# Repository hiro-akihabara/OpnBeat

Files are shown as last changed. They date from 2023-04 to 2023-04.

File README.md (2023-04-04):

# About the Project
OpnBeat is Arduino based open source Lo-fi sampler project.<br>
It's designed to be low cost, easy to understand, to use and to make.

<br>
3D rendered image by Blender

<br>
PCB

<a href="http://www.youtube.com/watch?feature=player_embedded&v=SjGH37jxioc
" target="_blank">IMAGE ALT TEXT HERE</a><br>
Demo video

# Why this project is beneficial

# Project Status
I have just developed its prototype (Ver.3), POC (Proof of concept), MVP (Minimum Viable Product) whatever it's called including hardware. But I need supports especially about improving its farmware because I'm mainly an electric engineer and not so good at programming.

# Links
* project on Hackaday.io<br>
[OpnBeat / DIY Lo-fi Sampler with ISD1700 series](https://hackaday.io/project/190273-opnbeat-diy-lo-fi-sampler-with-isd1700-serie

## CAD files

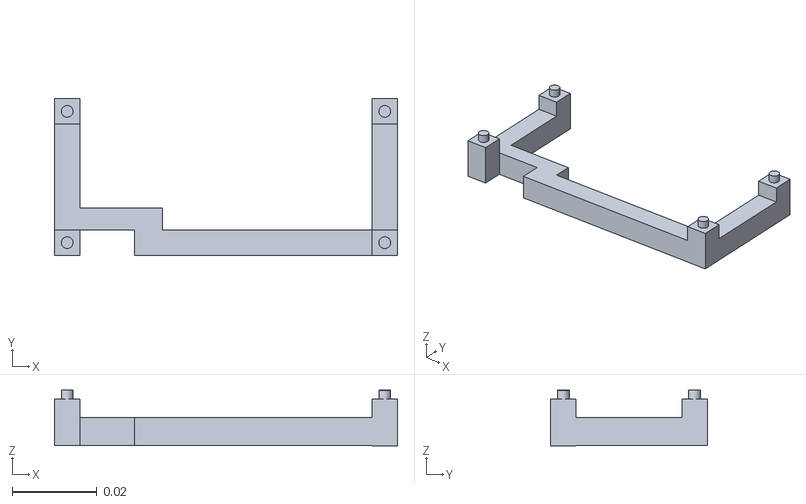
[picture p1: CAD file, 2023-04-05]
3D_printer/PROTO3/OpnBeat_PROTO_3LCD_holder_20230309.stl
0.081 x 0.037 x 0.0131

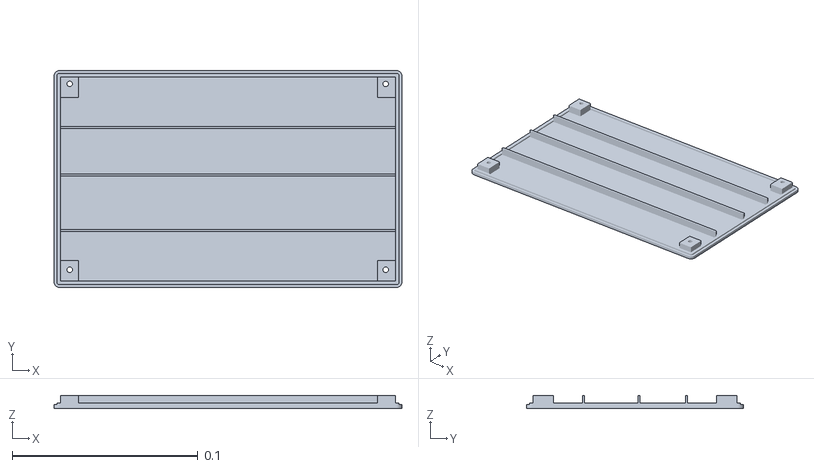
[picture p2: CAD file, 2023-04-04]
3D_printer/PROTO3/OpnBeat_PROTO_3_bottom_case_20230331.stl
0.187 x 0.117 x 0.00688

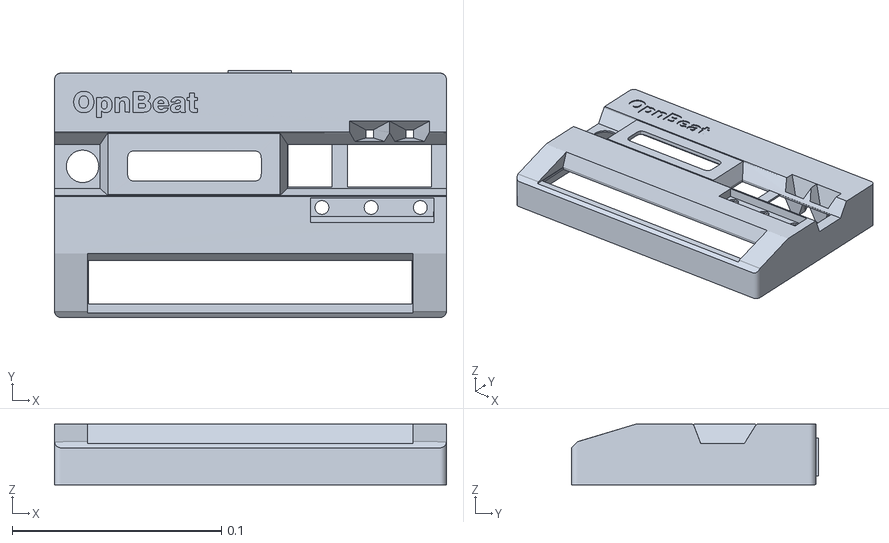
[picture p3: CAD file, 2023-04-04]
3D_printer/PROTO3/OpnBeat_PROTO_3_upper_case_20230331.stl
0.187 x 0.118 x 0.0291

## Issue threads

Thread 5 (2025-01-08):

3D print files not working

KeenVox, 2025-01-08:
Hi,

the .stl files are not working. Is there a possibility to get working ones? :)

hiro-akihabara, 2025-01-09:
Hi,

For which version of PCB are you looking for the cases?

Can I see your PCB?

Best regards,

Hiro

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

KeenVox, 2025-01-09:
Hi Hiro,

here's the pcb:

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

hiro-akihabara, 2025-01-11:
Hi,

I'm sorry for my late reply.
I developed it in 2023 and it took time for me to remember it.

In my environment, the 3D .stl can be sliced with slicer software although
the model has some errors.
[image: image.png]

What do you mean that the .STL files are not working?
Is it impossible to slice because of the model errors?
If slicing has no problem, you should take care of its printing orientation
for reducing printing time.

Best regards,
Hiro

2025年1月9日(木) 23:45 KeenVox ***@***.***>:

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

KeenVox, 2025-01-11:
Hi,
no worrys.

I don't have a 3D Printer at my disposal, so I wanted to use a printer service like JLCPCBs or a local one and neither can process the .stl files. I had a friend of mine check the .stl files and his program gives error on the measurements. The propotions seems to be alle wrong.
So there thems to be a problem in the meta data of the .stl files...

hiro-akihabara, 2025-01-11:
Hi,

I understand the problem.
Maybe you should try the scale x1000.
I experienced such a problem because the unit (mm or m) is different among
my environment, your friend and printing services.

Best regards,
Hiro

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

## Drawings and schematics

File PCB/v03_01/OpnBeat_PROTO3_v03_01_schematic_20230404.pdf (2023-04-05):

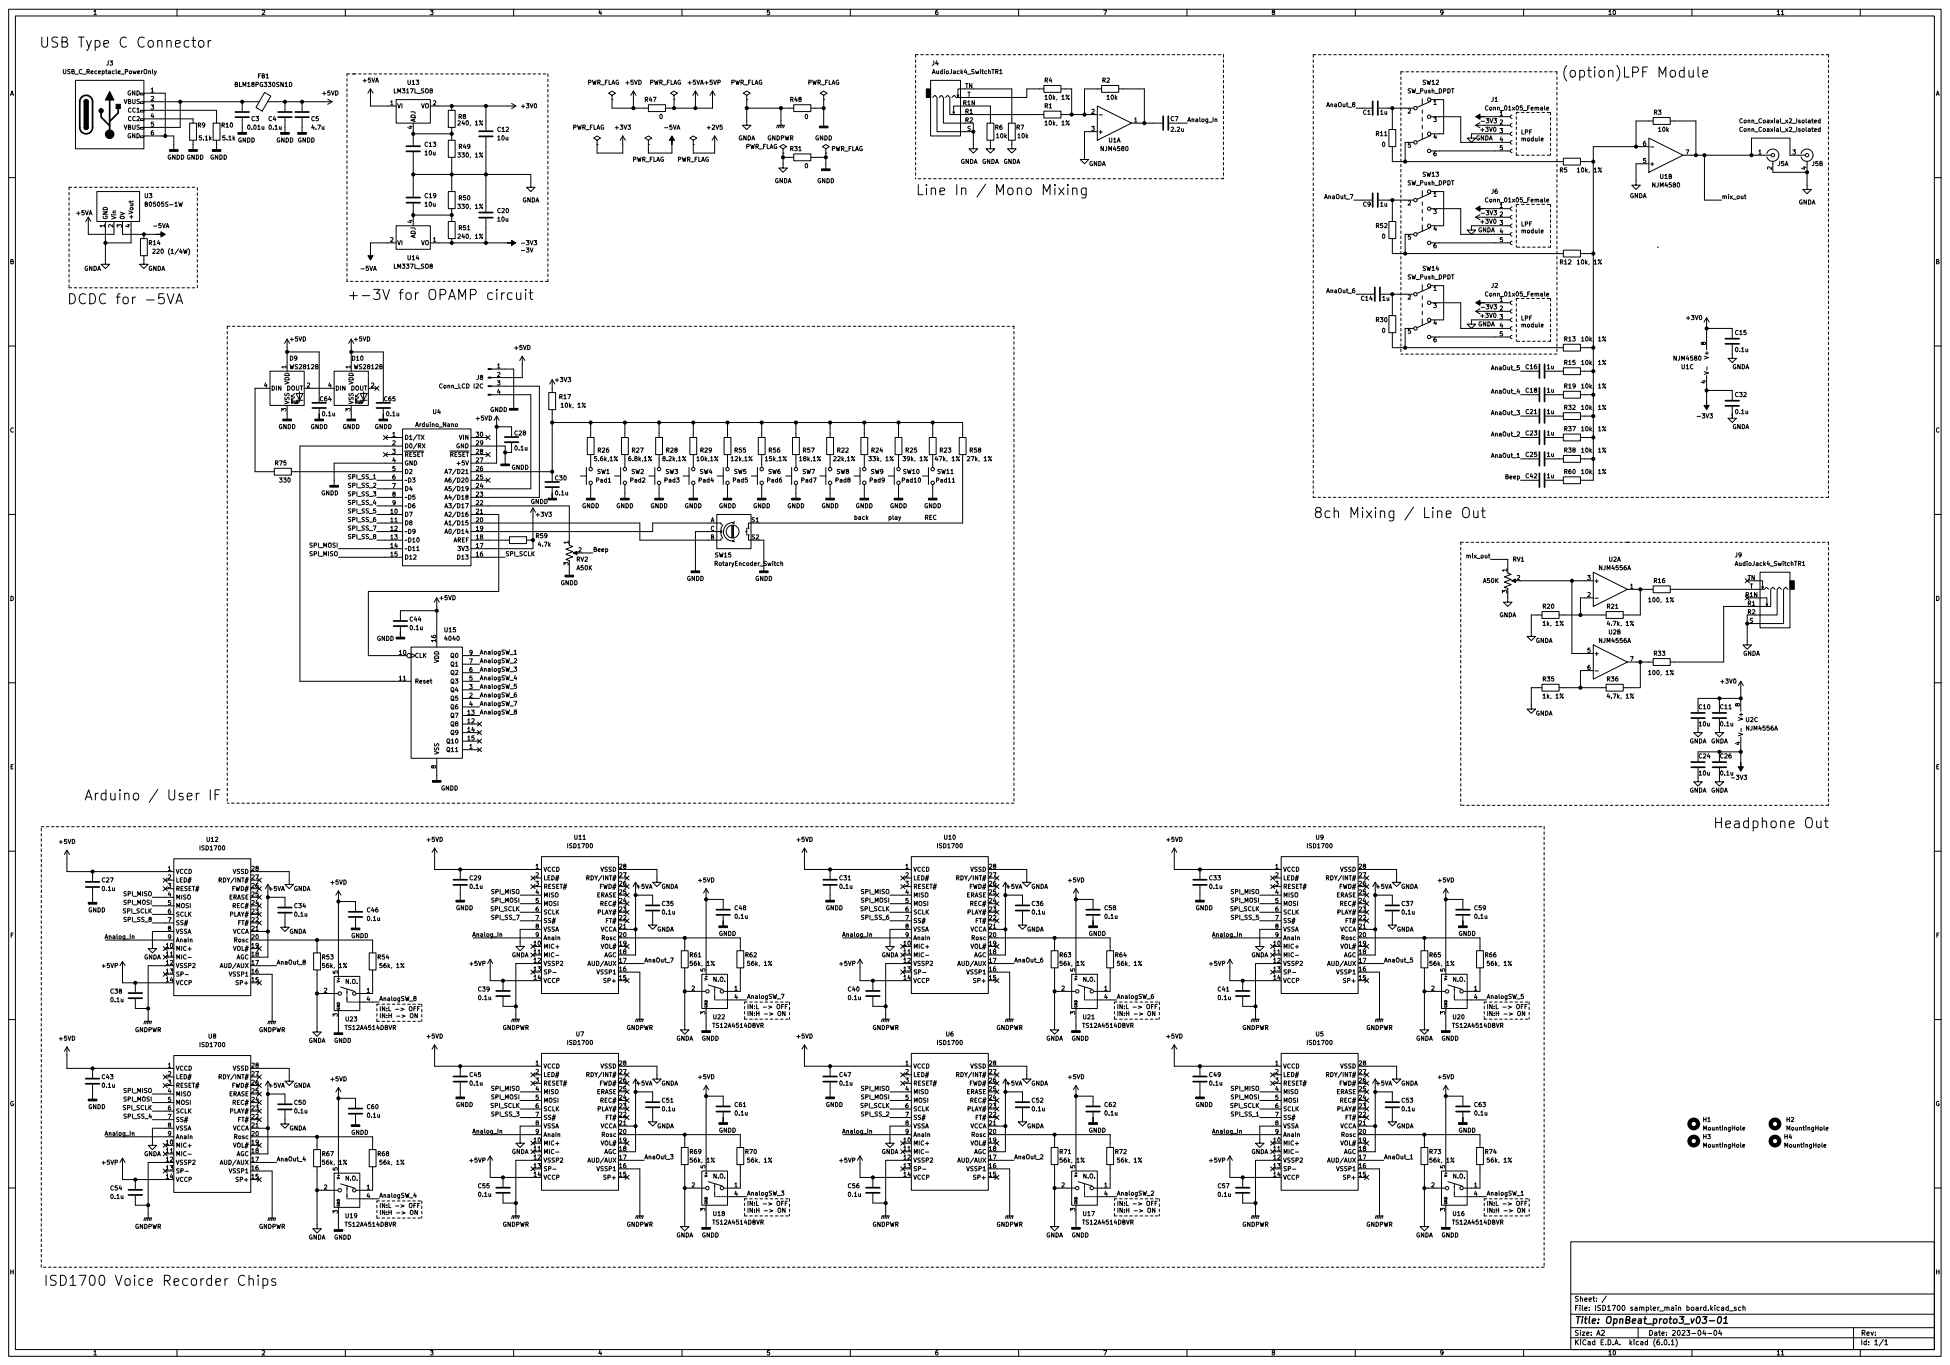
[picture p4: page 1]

Line In / Mono Mixing

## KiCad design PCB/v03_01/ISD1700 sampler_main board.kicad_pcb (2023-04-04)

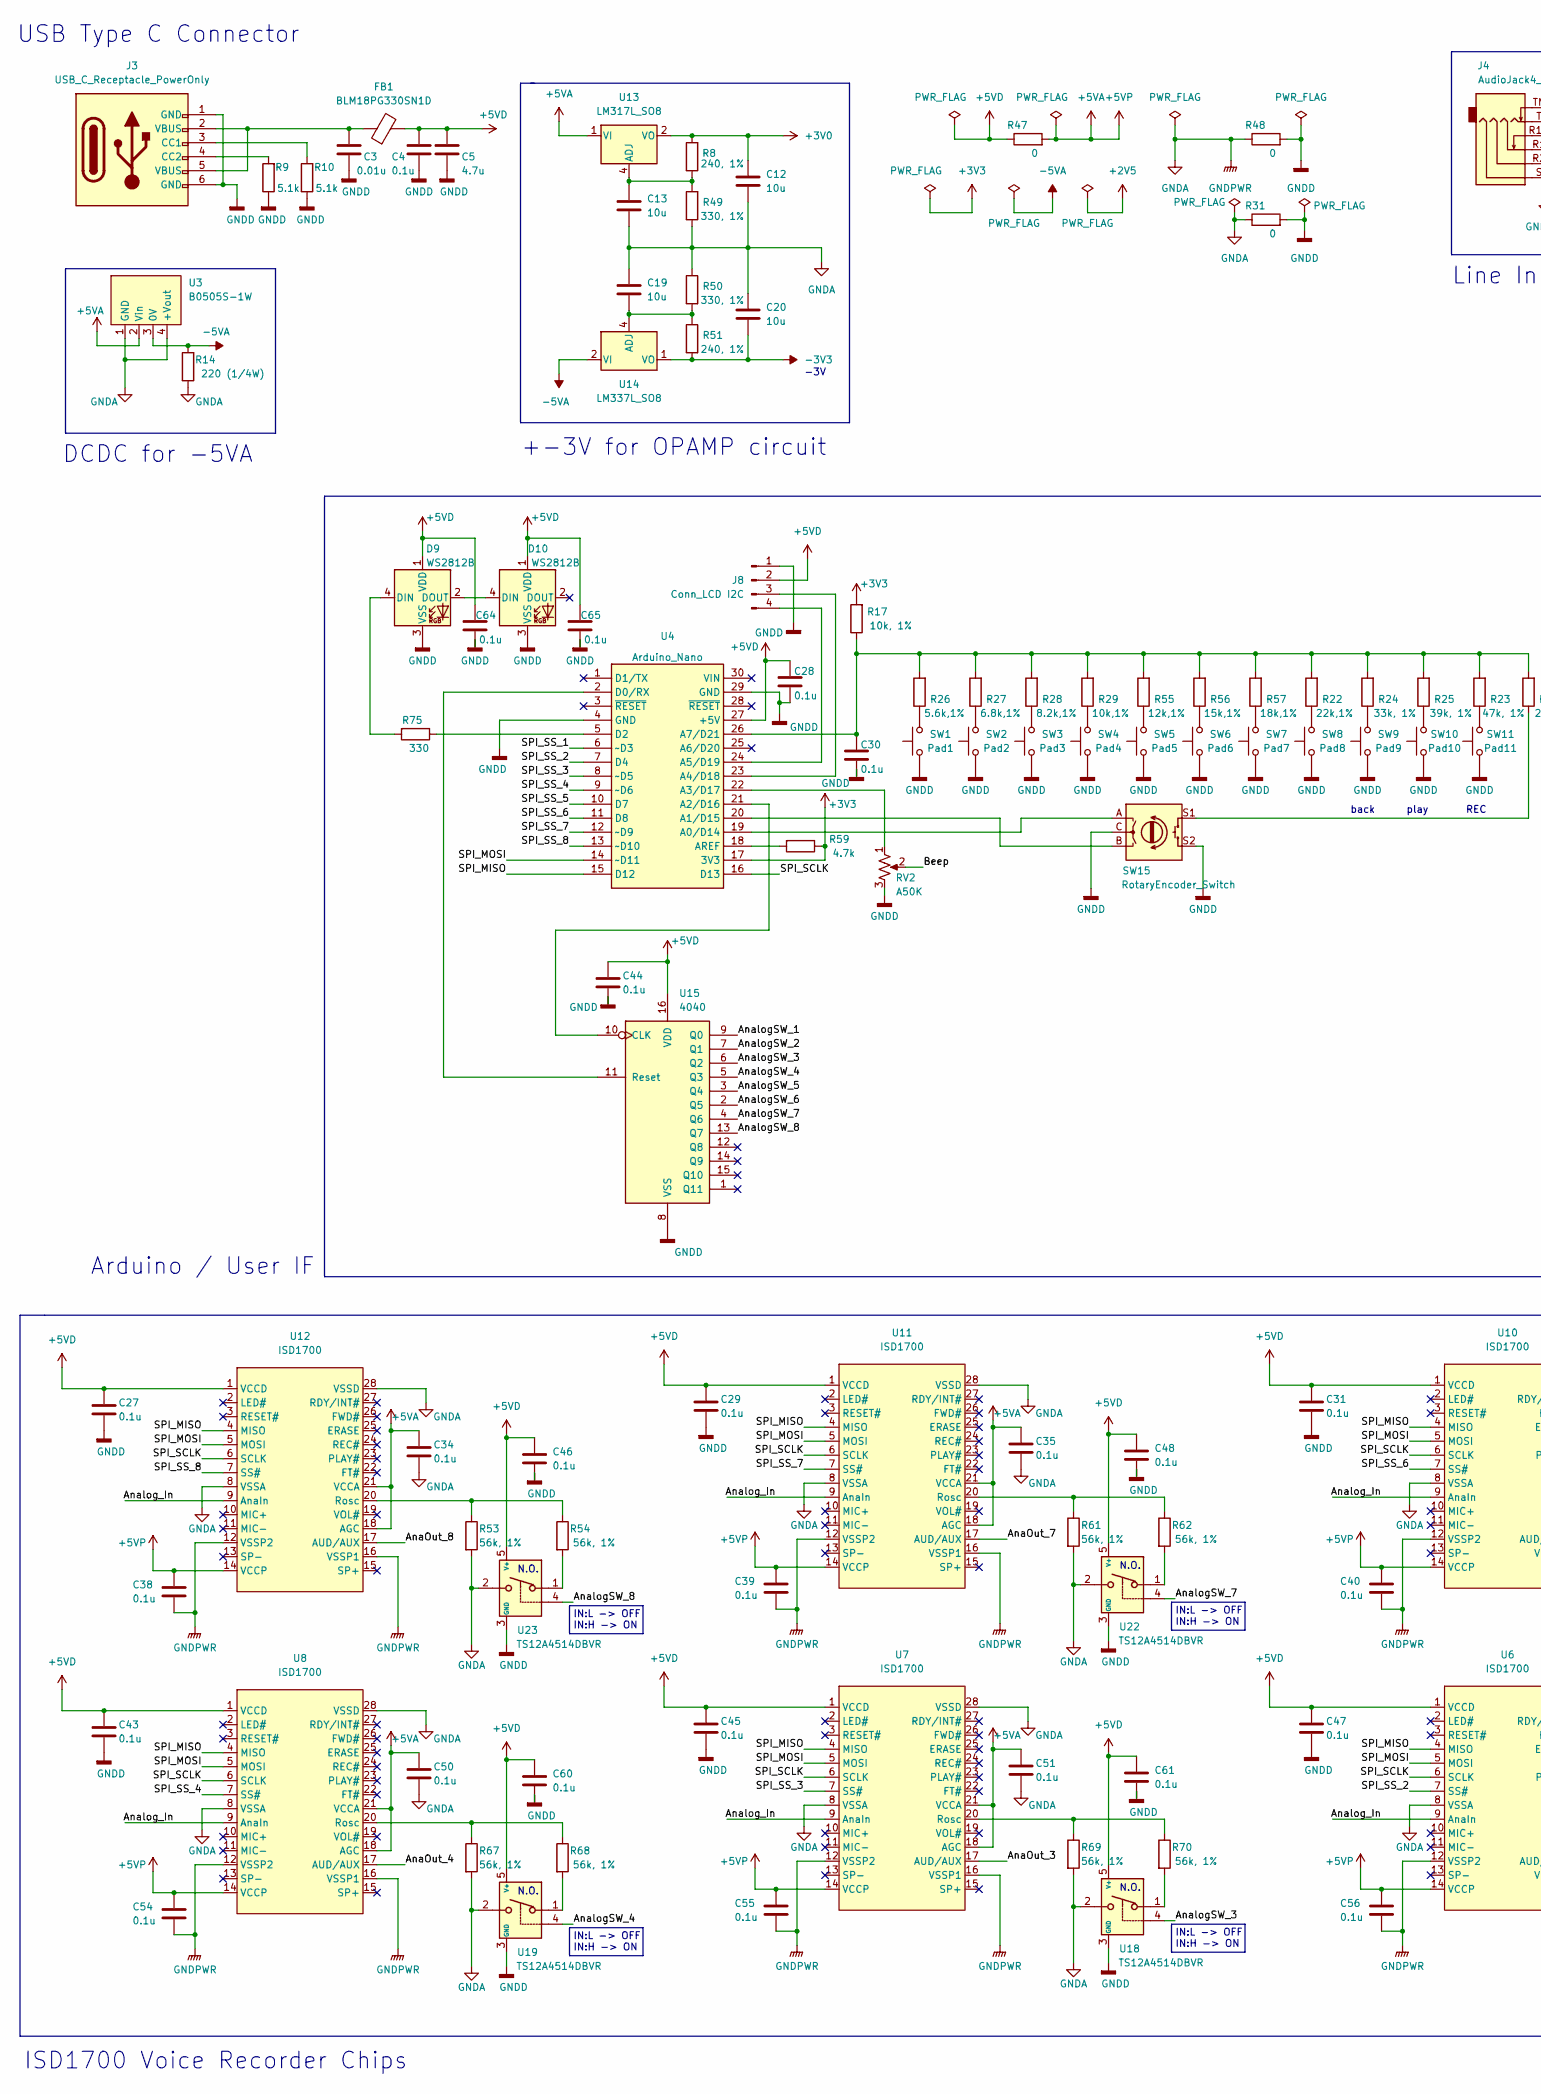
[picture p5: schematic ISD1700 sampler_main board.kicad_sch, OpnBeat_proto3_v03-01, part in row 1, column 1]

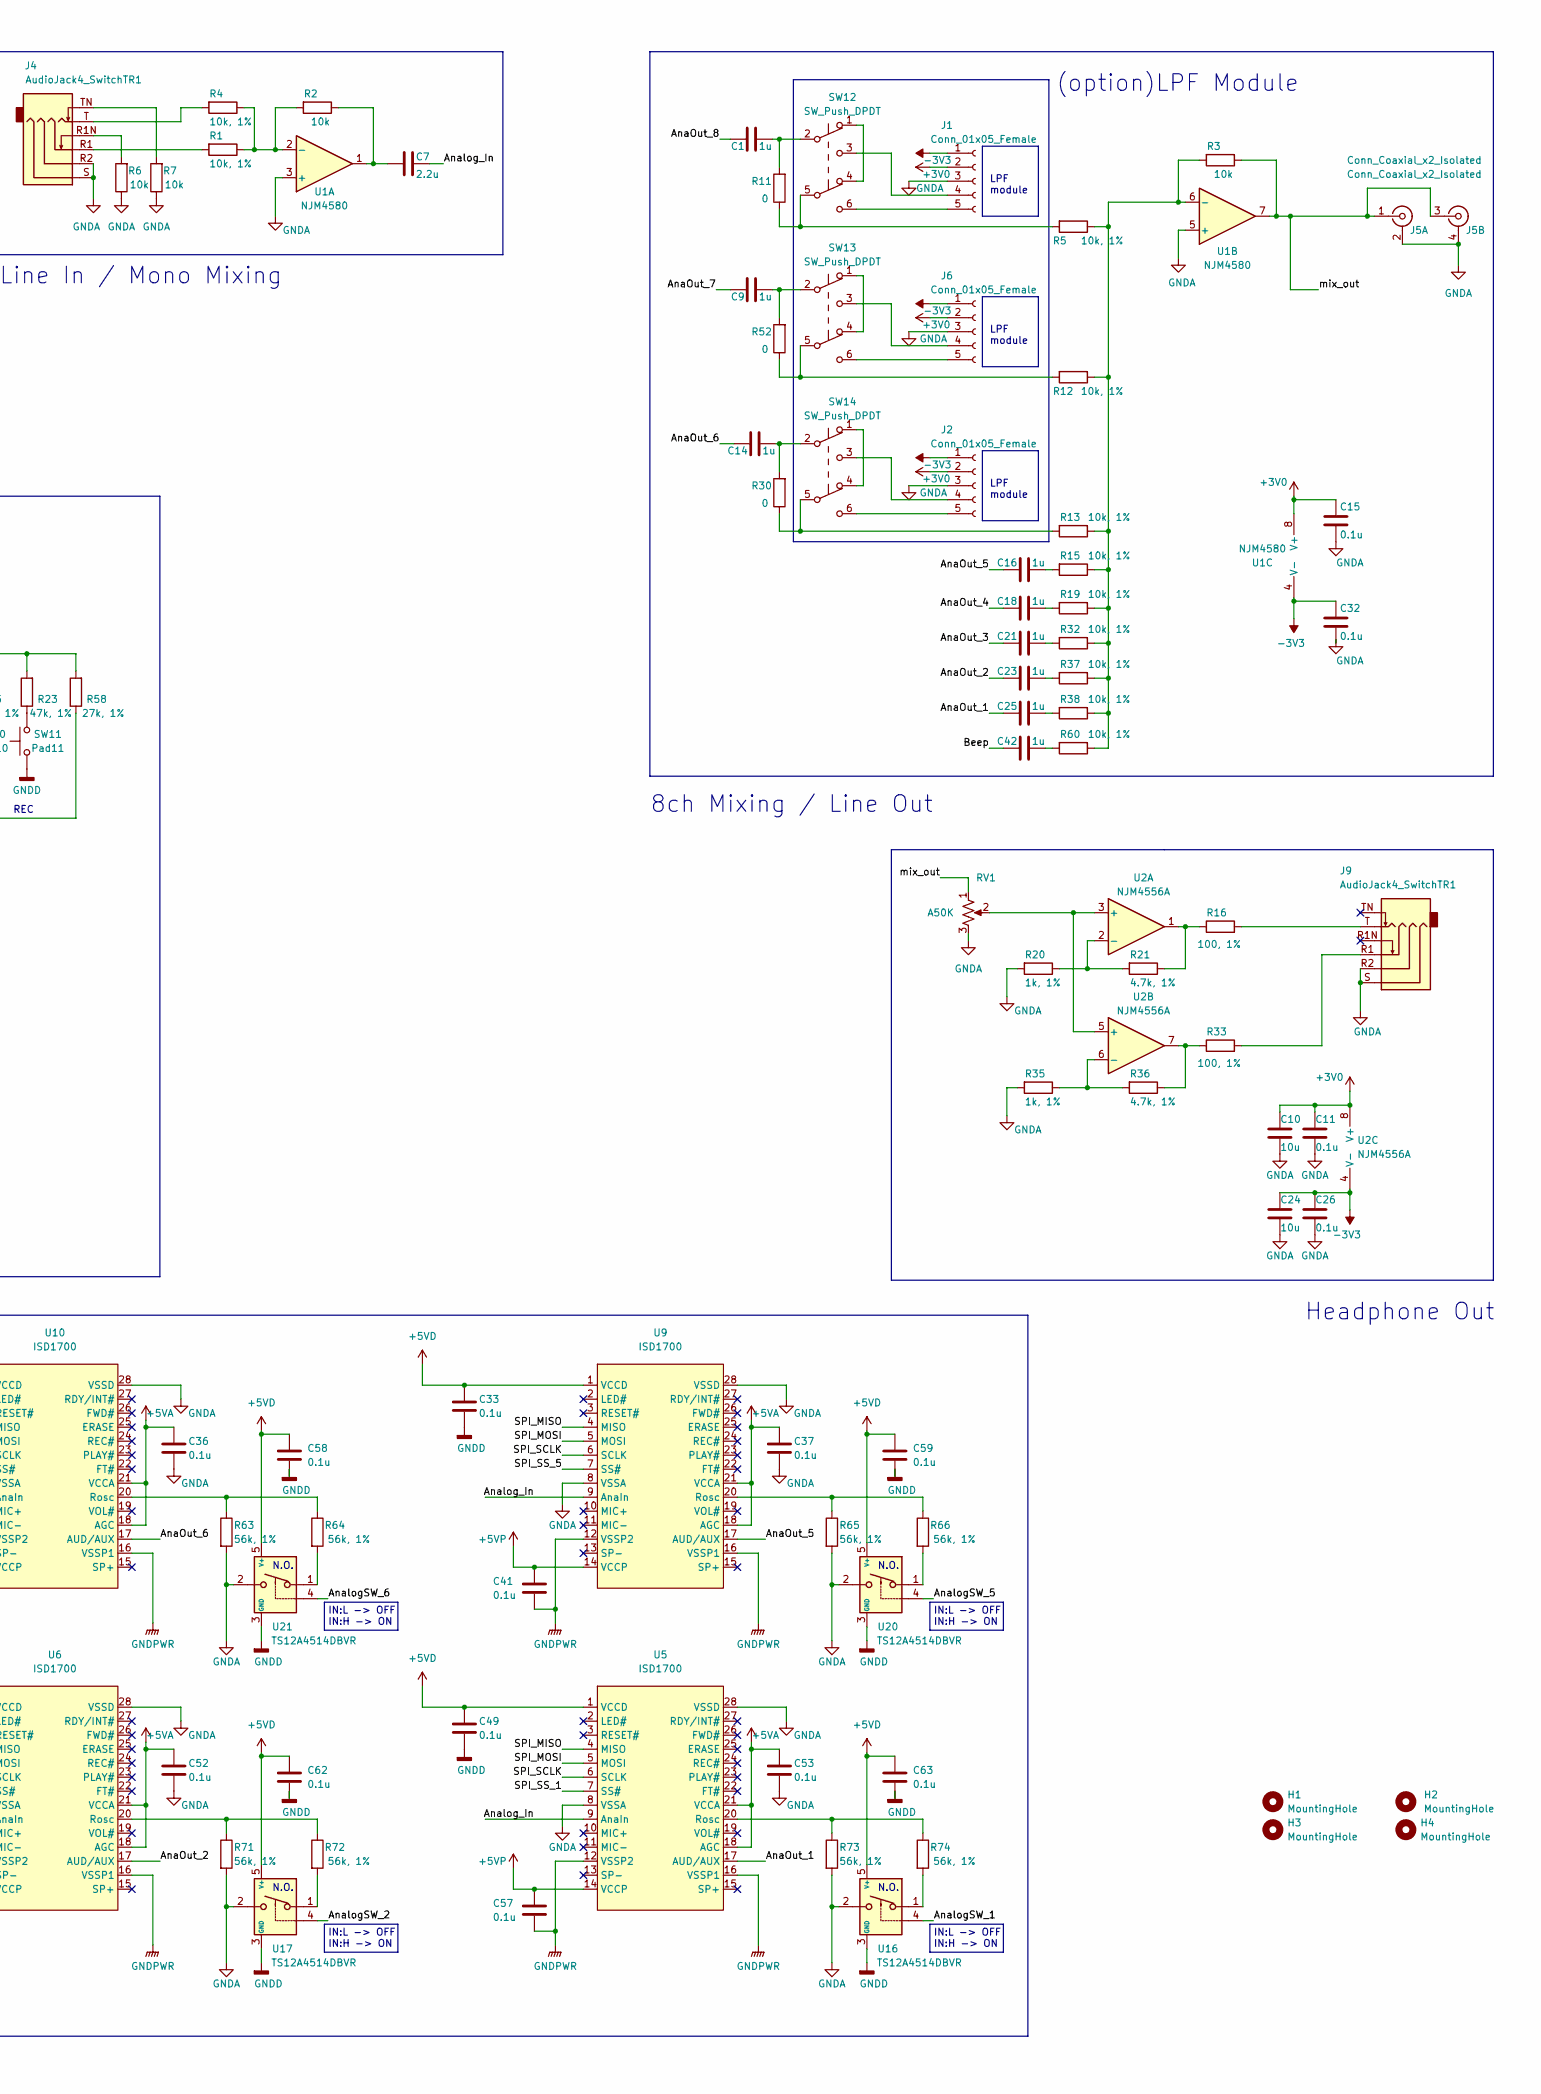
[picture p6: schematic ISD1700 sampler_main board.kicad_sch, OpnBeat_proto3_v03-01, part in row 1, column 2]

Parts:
C1, C9, C14, C16, C18, C21, C23, C25, C42: 1u; C_0603_1608Metric
C3: 0.01u; C_0603_1608Metric
C4, C11, C15, C26, C27, C28, C29, C30, C31, C32, C33, C34, C35, C36, C37, C38, C39, C40, C41, C43, C44, C45, C46, C47, C48, C49, C50, C51, C52, C53, C54, C55, C56, C57, C58, C59, C60, C61, C62, C63, C64, C65: 0.1u; C_0603_1608Metric
C5: 4.7u; C_0603_1608Metric
C7: 2.2u; C_0603_1608Metric
C10, C12, C13, C19, C20, C24: 10u; C_0603_1608Metric
D9, D10: WS2812B; LED_WS2812B_PLCC4_5.0x5.0mm_P3.2mm
FB1: BLM18PG330SN1D; C_0603_1608Metric
H1, H2, H3, H4: MountingHole; MountingHole_3.2mm_M3
J1, J2, J6: Conn_01x05_Female; PinSocket_1x05_P2.54mm_Vertical
J3: USB_C_Receptacle_PowerOnly; USB C only Power
J4, J9: AudioJack4_SwitchTR1; Jack_3.5mm_PJ31060-I_Horizontal
J5: Conn_Coaxial_x2_Isolated; RCA-214
J8: Conn_LCD I2C; PinSocket_1x04_P2.54mm_Vertical
R1, R4, R5, R12, R13, R15, R17, R19, R32, R37, R38, R60: 10k, 1%; R_0603_1608Metric
R2, R3, R6, R7: 10k; R_0603_1608Metric
R8, R51: 240, 1%; R_0603_1608Metric
R9, R10: 5.1k; R_0603_1608Metric
R11, R30, R52: 0; R_0603_1608Metric
R14: 220 (1/4W); R_1206_3216Metric
R16, R33: 100, 1%; R_0603_1608Metric
R20, R35: 1k, 1%; R_0603_1608Metric
R21, R36: 4.7k, 1%; R_0603_1608Metric
R22: 22k,1%; R_0603_1608Metric
R23: 47k, 1%; R_0603_1608Metric
R24: 33k, 1%; R_0603_1608Metric
R25: 39k, 1%; R_0603_1608Metric
R26: 5.6k,1%; R_0603_1608Metric
R27: 6.8k,1%; R_0603_1608Metric
R28: 8.2k,1%; R_0603_1608Metric
R29: 10k,1%; R_0603_1608Metric
R31, R47, R48: 0; R_0805_2012Metric
R49, R50: 330, 1%; R_0603_1608Metric
R53, R54, R61, R62, R63, R64, R65, R66, R67, R68, R69, R70, R71, R72, R73, R74: 56k, 1%; R_0603_1608Metric
R55: 12k,1%; R_0603_1608Metric
R56: 15k,1%; R_0603_1608Metric
R57: 18k,1%; R_0603_1608Metric
R58: 27k, 1%; R_0603_1608Metric
R59: 4.7k; R_0603_1608Metric
R75: 330; R_0603_1608Metric
RV1, RV2: A50K; Potentiometer_Bourns_PTV09A-2_Single_Horizontal
SW1: Pad1; SW_Cherry_MX_PCB_1.00u
SW2: Pad2; SW_Cherry_MX_PCB_1.00u
SW3: Pad3; SW_Cherry_MX_PCB_1.00u
SW4: Pad4; SW_Cherry_MX_PCB_1.00u
SW5: Pad5; SW_Cherry_MX_PCB_1.00u
SW6: Pad6; SW_Cherry_MX_PCB_1.00u
SW7: Pad7; SW_Cherry_MX_PCB_1.00u
SW8: Pad8; SW_Cherry_MX_PCB_1.00u
SW9: Pad9; SW_Cherry_MX_PCB_1.00u
SW10: Pad10; SW_Cherry_MX_PCB_1.00u
SW11: Pad11; SW_Cherry_MX_PCB_1.00u
SW12, SW13, SW14: SW_Push_DPDT; Push SW DPDT
SW15: RotaryEncoder_Switch; RotaryEncoder_Alps_EC11E-Switch_Vertical_H20mm_CircularMoun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
U1: NJM4580; TSSOP-8_4.4x3mm_P0.65mm
U2: NJM4556A; TSSOP-8_4.4x3mm_P0.65mm
U3: B0505S-1W
U4: Arduino_Nano
U5, U6, U7, U8, U9, U10, U11, U12: ISD1700; SOIC-28W_7.5x17.9mm_P1.27mm
U13: LM317L_SO8; SOIC-8_3.9x4.9mm_P1.27mm
U14: LM337L_SO8; SOIC-8_3.9x4.9mm_P1.27mm
U15: 4040; SOIC-16_3.9x9.9mm_P1.27mm
U16, U17, U18, U19, U20, U21, U22, U23: TS12A4514DBVR; SOT-23-5

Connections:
+3V0: C10.1, C11.1, C12.1, C15.1, J1.2, J2.2, J6.2, R8.2, U1.8 (V+), U2.8 (V+), U13.2 (VO), U13.3 (VO), U13.6 (VO), U13.7 (VO)
+3V3: R17.2, R59.1, U4.17 (3V3)
+5VA: C34.1, C35.1, C36.1, C37.1, C38.1, C39.1, C40.1, C41.1, C50.1, C51.1, C52.1, C53.1, C54.1, C55.1, C56.1, C57.1, R47.2, U3.2 (Vin), U5.14 (VCCP), U5.18 (AGC), U5.21 (VCCA), U6.14 (VCCP), U6.18 (AGC), U6.21 (VCCA), U7.14 (VCCP), U7.18 (AGC), U7.21 (VCCA), U8.14 (VCCP), U8.18 (AGC), U8.21 (VCCA), U9.14 (VCCP), U9.18 (AGC), U9.21 (VCCA), U10.14 (VCCP), U10.18 (AGC), U10.21 (VCCA), U11.14 (VCCP), U11.18 (AGC), U11.21 (VCCA), U12.14 (VCCP), U12.18 (AGC), U12.21 (VCCA), U13.1 (VI)
+5VD: C4.1, C5.1, C27.1, C28.1, C29.1, C31.1, C33.1, C43.1, C44.1, C45.1, C46.1, C47.1, C48.1, C49.1, C58.1, C59.1, C60.1, C61.1, C62.1, C63.1, C64.1, C65.1, D9.1 (VDD), D10.1 (VDD), FB1.2, J8.2, R47.1, U4.27 (+5V), U5.1 (VCCD), U6.1 (VCCD), U7.1 (VCCD), U8.1 (VCCD), U9.1 (VCCD), U10.1 (VCCD), U11.1 (VCCD), U12.1 (VCCD), U15.16 (VDD), U16.5 (V+), U17.5 (V+), U18.5 (V+), U19.5 (V+), U20.5 (V+), U21.5 (V+), U22.5 (V+), U23.5 (V+)
-3V3: C20.1, C24.1, C26.1, C32.1, J1.1, J2.1, J6.1, R51.2, U1.4 (V-), U2.4 (V-), U14.1 (VO)
-5VA: R14.2, U3.3 (0V), U14.2 (VI), U14.3 (VI), U14.6 (VI), U14.7 (VI)
/AnaOut_1: C25.2, U5.17 (AUD/AUX)
/AnaOut_2: C23.2, U6.17 (AUD/AUX)
/AnaOut_3: C21.2, U7.17 (AUD/AUX)
/AnaOut_4: C18.2, U8.17 (AUD/AUX)
/AnaOut_5: C16.2, U9.17 (AUD/AUX)
/AnaOut_6: C14.2, U10.17 (AUD/AUX)
/AnaOut_7: C9.2, U11.17 (AUD/AUX)
/AnaOut_8: C1.2, U12.17 (AUD/AUX)
/AnalogSW_1: U15.9 (Q0), U16.4
/AnalogSW_2: U15.7 (Q1), U17.4
/AnalogSW_3: U15.6 (Q2), U18.4
/AnalogSW_4: U15.5 (Q3), U19.4
/AnalogSW_5: U15.3 (Q4), U20.4
/AnalogSW_6: U15.2 (Q5), U21.4
/AnalogSW_7: U15.4 (Q6), U22.4
/AnalogSW_8: U15.13 (Q7), U23.4
/Analog_In: C7.1, U5.9 (AnaIn), U6.9 (AnaIn), U7.9 (AnaIn), U8.9 (AnaIn), U9.9 (AnaIn), U10.9 (AnaIn), U11.9 (AnaIn), U12.9 (AnaIn)
/Beep: C42.2, RV2.2
/SPI_MISO: U4.15 (D12), U5.4 (MISO), U6.4 (MISO), U7.4 (MISO), U8.4 (MISO), U9.4 (MISO), U10.4 (MISO), U11.4 (MISO), U12.4 (MISO)
/SPI_MOSI: U4.14 (~D11), U5.5 (MOSI), U6.5 (MOSI), U7.5 (MOSI), U8.5 (MOSI), U9.5 (MOSI), U10.5 (MOSI), U11.5 (MOSI), U12.5 (MOSI)
/SPI_SCLK: U4.16 (D13), U5.6 (SCLK), U6.6 (SCLK), U7.6 (SCLK), U8.6 (SCLK), U9.6 (SCLK), U10.6 (SCLK), U11.6 (SCLK), U12.6 (SCLK)
/SPI_SS_1: U4.6 (~D3), U5.7 (SS#)
/SPI_SS_2: U4.7 (D4), U6.7 (SS#)
/SPI_SS_3: U4.8 (~D5), U7.7 (SS#)
/SPI_SS_4: U4.9 (~D6), U8.7 (SS#)
/SPI_SS_5: U4.10 (D7), U9.7 (SS#)
/SPI_SS_6: U4.11 (D8), U10.7 (SS#)
/SPI_SS_7: U4.12 (~D9), U11.7 (SS#)
/SPI_SS_8: U4.13 (~D10), U12.7 (SS#)
/mix_out: J5.1 (In1), J5.3 (In2), R3.1, RV1.1, U1.7
GNDA: C10.2, C11.2, C12.2, C13.2, C15.2, C19.2, C20.2, C24.2, C26.2, C32.2, C34.2, C35.2, C36.2, C37.2, C38.2, C39.2, C40.2, C41.2, C50.2, C51.2, C52.2, C53.2, C54.2, C55.2, C56.2, C57.2, J1.3, J2.3, J4.R2, J4.S, J5.2 (Ext1), J5.4 (Ext2), J6.3, J9.R2, J9.S, R6.1, R7.1, R14.1, R20.2, R31.1, R35.2, R48.1, R49.1, R50.1, R53.2, R61.2, R63.2, R65.2, R67.2, R69.2, R71.2, R73.2, RV1.3, U1.3 (+), U1.5 (+), U3.1 (GND), U3.4 (+Vout), U5.8 (VSSA), U5.12 (VSSP2), U5.16 (VSSP1), U5.28 (VSSD), U6.8 (VSSA), U6.12 (VSSP2), U6.16 (VSSP1), U6.28 (VSSD), U7.8 (VSSA), U7.12 (VSSP2), U7.16 (VSSP1), U7.28 (VSSD), U8.8 (VSSA), U8.12 (VSSP2), U8.16 (VSSP1), U8.28 (VSSD), U9.8 (VSSA), U9.12 (VSSP2), U9.16 (VSSP1), U9.28 (VSSD), U10.8 (VSSA), U10.12 (VSSP2), U10.16 (VSSP1), U10.28 (VSSD), U11.8 (VSSA), U11.12 (VSSP2), U11.16 (VSSP1), U11.28 (VSSD), U12.8 (VSSA), U12.12 (VSSP2), U12.16 (VSSP1), U12.28 (VSSD), U16.2, U17.2, U18.2, U19.2, U20.2, U21.2, U22.2, U23.2
GNDD: C3.2, C4.2, C5.2, C27.2, C28.2, C29.2, C30.2, C31.2, C33.2, C43.2, C44.2, C45.2, C46.2, C47.2, C48.2, C49.2, C58.2, C59.2, C60.2, C61.2, C62.2, C63.2, C64.2, C65.2, D9.3 (VSS), D10.3 (VSS), J3.1 (GND), J3.6 (GND), J8.1, R9.1, R10.1, R31.2, R48.2, RV2.3, SW1.1, SW2.1, SW3.1, SW4.1, SW5.1, SW6.1, SW7.1, SW8.1, SW9.1, SW10.1, SW11.1, SW15.C, SW15.S2, U4.4 (GND), U4.29 (GND), U15.8 (VSS), U16.3 (GND), U17.3 (GND), U18.3 (GND), U19.3 (GND), U20.3 (GND), U21.3 (GND), U22.3 (GND), U23.3 (GND)
unnamed: C1.1, R11.2, SW12.2 (B)
unnamed: C3.1, FB1.1, J3.2 (VBUS), J3.5 (VBUS)
unnamed: C7.2, R2.1, U1.1
unnamed: C9.1, R52.2, SW13.2 (B)
unnamed: C13.1, R8.1, R49.2, U13.4 (ADJ)
unnamed: C14.1, R30.2, SW14.2 (B)
unnamed: C16.1, R15.2
unnamed: C18.1, R19.2
unnamed: C19.1, R50.2, R51.1, U14.4 (ADJ)
unnamed: C21.1, R32.2
unnamed: C23.1, R37.2
unnamed: C25.1, R38.2
unnamed: C30.1, R17.1, R22.2, R23.2, R24.2, R25.2, R26.2, R27.2, R28.2, R29.2, R55.2, R56.2, R57.2, R58.2, U4.26 (A7/D21)
unnamed: C42.1, R60.2
unnamed: D9.4 (DIN), R75.2
unnamed: D9.2 (DOUT), D10.4 (DIN)
unnamed: J1.4, SW12.3 (C)
unnamed: J1.5, SW12.6 (C)
unnamed: J2.4, SW14.3 (C)
unnamed: J2.5, SW14.6 (C)
unnamed: J3.3 (CC1), R10.2
unnamed: J3.4 (CC2), R9.2
unnamed: J4.R1, R1.2
unnamed: J4.R1N, R6.2
unnamed: J4.T, R4.2
unnamed: J4.TN, R7.2
unnamed: J6.4, SW13.3 (C)
unnamed: J6.5, SW13.6 (C)
unnamed: J8.3, U4.23 (A4/D18)
unnamed: J8.4, U4.24 (A5/D19)
unnamed: J9.R1, R33.2
unnamed: J9.T, R16.2
unnamed: R1.1, R2.2, R4.1, U1.2 (-)
unnamed: R5.2, R11.1, SW12.5 (B)
unnamed: R3.2, R5.1, R12.1, R13.1, R15.1, R19.1, R32.1, R37.1, R38.1, R60.1, U1.6 (-)
unnamed: R12.2, R52.1, SW13.5 (B)
unnamed: R13.2, R30.1, SW14.5 (B)
unnamed: R16.1, R21.1, U2.1
unnamed: R20.1, R21.2, U2.2 (-)
unnamed: R22.1, SW8.2
unnamed: R23.1, SW11.2
unnamed: R24.1, SW9.2
unnamed: R25.1, SW10.2
unnamed: R26.1, SW1.2
unnamed: R27.1, SW2.2
unnamed: R28.1, SW3.2
unnamed: R29.1, SW4.2
unnamed: R33.1, R36.1, U2.7
unnamed: R35.1, R36.2, U2.6 (-)
unnamed: R53.1, R54.1, U12.20 (Rosc)
unnamed: R54.2, U23.1
unnamed: R55.1, SW5.2
unnamed: R56.1, SW6.2
unnamed: R57.1, SW7.2
unnamed: R58.1, SW15.S1
unnamed: R59.2, U4.18 (AREF)
unnamed: R61.1, R62.1, U11.20 (Rosc)
unnamed: R62.2, U22.1
unnamed: R63.1, R64.1, U10.20 (Rosc)
unnamed: R64.2, U21.1
unnamed: R65.1, R66.1, U9.20 (Rosc)
unnamed: R66.2, U20.1
unnamed: R67.1, R68.1, U8.20 (Rosc)
unnamed: R68.2, U19.1
unnamed: R69.1, R70.1, U7.20 (Rosc)
unnamed: R70.2, U18.1
unnamed: R71.1, R72.1, U6.20 (Rosc)
unnamed: R72.2, U17.1
unnamed: R73.1, R74.1, U5.20 (Rosc)
unnamed: R74.2, U16.1
unnamed: R75.1, U4.5 (D2)
unnamed: RV1.2, U2.3 (+), U2.5 (+)
unnamed: RV2.1, U4.22 (A3/D17)
unnamed: SW12.1 (A), SW12.4 (A)
unnamed: SW13.1 (A), SW13.4 (A)
unnamed: SW14.1 (A), SW14.4 (A)
unnamed: SW15.A, U4.19 (A0/D14)
unnamed: SW15.B, U4.20 (A1/D15)
unnamed: U4.21 (A2/D16), U15.10 (CLK)
unnamed: U4.2 (D0/RX), U15.11 (Reset)

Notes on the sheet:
Headphone Out
IN:L -> OFF IN:H -> ON
N.O.
(option)LPF Module
DCDC for -5VA
Line In / Mono Mixing
+-3V for OPAMP circuit
LPF module
ISD1700 Voice Recorder Chips
8ch Mixing / Line Out
play
back
REC
USB Type C Connector
Arduino / User IF
-3V

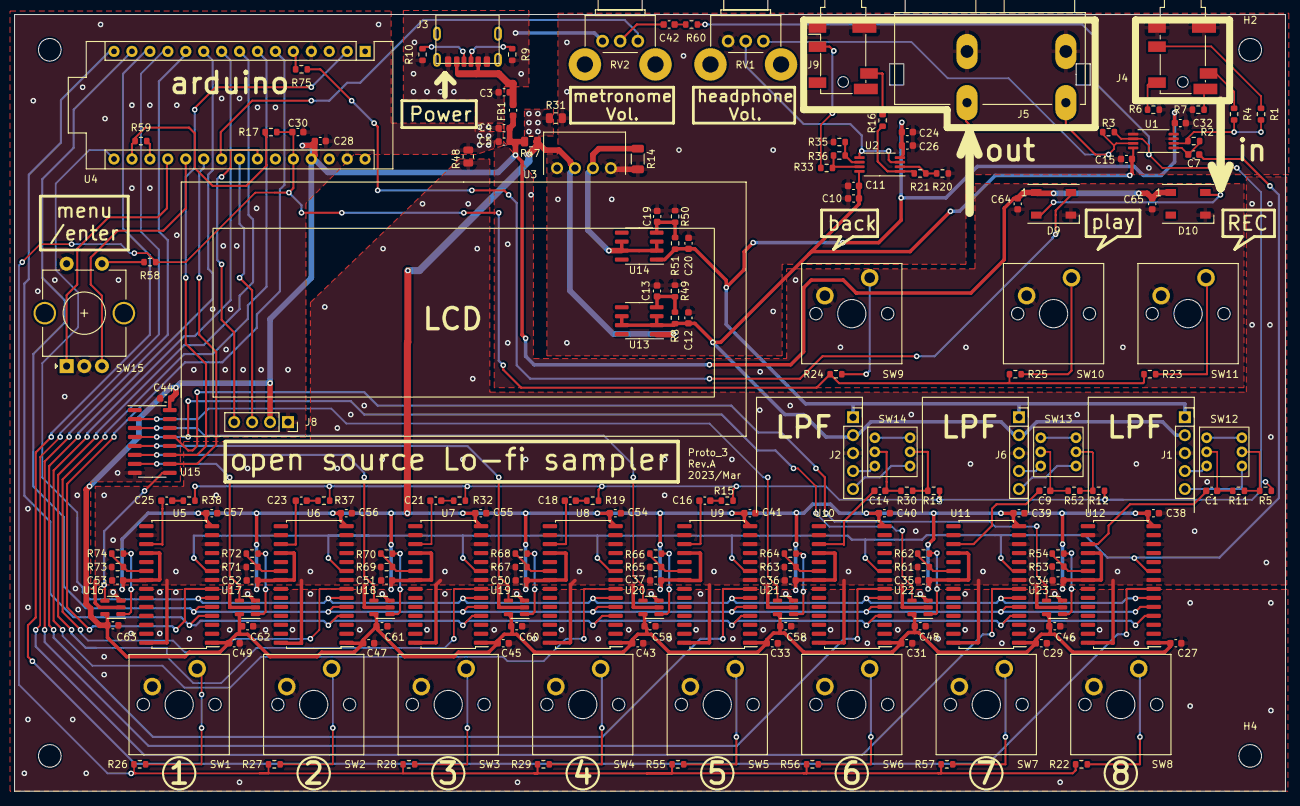
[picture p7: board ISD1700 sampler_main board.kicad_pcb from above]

Board: 2 copper layers, 180.0 x 110.0 mm, 180 parts (0 on the bottom side), 118 nets.

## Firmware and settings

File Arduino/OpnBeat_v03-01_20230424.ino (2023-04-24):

#include <EEPROM.h>
#include <TimerOne.h>
#include <ISD1700.h>
#include <LiquidCrystal_I2C.h>//library for 16x2 I2C LCD
#include <AnalogMultiButton.h>//library for reading all buttons and keys
#include <Adafruit_NeoPixel.h>//library for WS2812B full color LEDs
#define WITHOUT_BUTTON 1//without button option for ClickEncoder.h 
#include <ClickEncoder.h>//library forRotary Encorder

#define FIRST 0
#define SECOND 1
//for WS2812B full color LED
#define LED_PIN 2
#define LED_COUNT  2

//74HC4040 binary ripple counter controls to select analog switches for decide Rocs of ISD1700 
const byte analog_SW_reset = 0;
const byte analog_SW_clk = 16;
//for AnalogMultiButton
const byte BUTTONS_PIN = A7;
const byte BUTTONS_TOTAL = 12;//number of buttons and keys
const int BUTTONS_VALUES[BUTTONS_TOTAL] = {425,478,533,592,644,710,760,814,864,910,941,976};//actual ADC values with 3.3V reference
const byte pad_1 = 0;
const byte pad_2 = 1;
const byte pad_3 = 2;
const byte pad_4 = 3;
const byte pad_5 = 4;
const byte pad_6 = 5;
const byte pad_7 = 6;
const byte pad_8 = 7;
const byte button_encoder = 8;
const byte pad_back = 9;
const byte pad_play = 10;
const byte pad_rec = 11;

byte bpm = 100;//BPM, initial setting is 100
unsigned long time_now = 0;
byte Start_addr = 16;//playback start address, trimmed by rotary encoder
byte End_addr =16;//playback end address, trimmed by rotary encoder
byte Start_addr_1_ROM;//chip_1 start and end address stored in EEPROM
byte End_addr_1_ROM;
byte Start_addr_2_ROM;//chip_2 start and end address stored in EEPROM
byte End_addr_2_ROM;
byte Start_addr_3_ROM;//chip_3 start and end address stored in EEPROM
byte End_addr_3_ROM;
byte Start_addr_4_ROM;//chip_4 start and end address stored in EEPROM
byte End_addr_4_ROM;
byte Start_addr_5_ROM;//chip_5 start and end address stored in EEPROM
byte End_addr_5_ROM;
byte Start_addr_6_ROM;//chip_6 start and end address stored in EEPROM
byte End_addr_6_ROM;
byte Start_addr_7_ROM;//chip_7 start and end address stored in EEPROM
byte End_addr_7_ROM;
byte Start_addr_8_ROM;//chip_8 start and end address stored in EEPROM
byte End_addr_8_ROM;
int value;//value loads rotary encoder value
int last = 0;//last updated value of rotary encorder
byte chip_n = 1;//selected chip number of 1 to 8
byte rhythm_n = 1;//selected rhythm number of 1to8
byte track_n = 1;//selected track number of 1to8
byte menu_column = 0;
byte menu_row = 0;
byte cursor_row = 0;//cursor position on LCD
byte cursor_column = 0;//cursor position on LCD
boolean first_second = 0;//0:ryhthm 1st part (16bit), 1:ryhthm 2nd part (16bit)
byte volume[8];//volume of Chip1, Chip2, chip3....
byte volume_last[8];//previous updated volume
uint16_t pattern_eeprom = 0b0000000000000000;//load 16bit rhythm data from EEPROM
uint16_t pattern_eeprom_current = 0b0000000000000000;//rhythm data under being edited
uint16_t pattern_eeprom_last;//rhythm data last updated
byte pattern_digit;//only a digit of rhythm data for diplaying rhythm on LCD 
unsigned int eeprom_address = 0;
uint32_t rhythm_eeprom[8];//complete rhythm data which consists of patterns of 8 chips, load them from EEPROM
int key;//read ADC value to determine analog buttons input value
word SR0;//Status Resister 0 of ISD1700
uint8_t SR1;//Status Resister 1 of ISD1700
uint16_t apc = 0b0000100111100000;//initial APC resister value of ISD1700 which define operation mode of it.
uint16_t apc_ISDchipOne, apc_ISDchipTwo, apc_ISDchipThree, apc_ISDchipFour, apc_ISDchipFive, apc_ISDchipSix, apc_ISDchipSeven, apc_ISDchipEight;//APC resister values of each chips
byte track_data;//a digit of track data displayed on LCD in track edit mode
boolean value_updated = 0;//rotary encoder value, 1: updated, 0: not updated
boolean rec_status = 0;//Recording status in rhythm edit mode, 0: not recording, 1: recording
boolean play_status = 0;//Playing status in rhythm edit mode 0: pause, 1: playing
byte k;//used for counting in rhythm edit mode
byte REC_quality = 0b00000000;//this controls Rocs value and recording sound quality of chip 1 to 8, 0: Lo-RES, 1: Hi-RES

/////////////////////     custom character fonts for I2C LCD    //////////////////////////
const byte customChar_BAR[8] = {//separator used in track edit mode
  0b10000,
  0b10000,
  0b10000,
  0b10000,
  0b10000,
  0b10000,
  0b10000,
  0b10000
};

const byte customChar_vol_0[8] = {//vol.0 graphic used in level setting
  0b00000,
  0b00000,
  0b00000,
  0b00000,
  0b00000,
  0b00000,
  0b00000,
  0b00000
};

const byte customChar_vol_1[8] = {//vol.1 graphic used in level setting
  0b00000,
  0b00000,
  0b00000,
  0b00000,
  0b00000,
  0b00000,
  0b00000,
  0b11111
};

const byte customChar_vol_2[8] = {//vol.2 graphic used in level setting
  0b00000,
  0b00000,
  0b00000,
  0b00000,
  0b00000,
  0b00000,
  0b11111,
  0b11111
};

const byte customChar_vol_3[8] = {//vol.3 graphic used in level setting
  0b00000,
  0b00000,
  0b00000,
  0b00000,
  0b00000,
  0b11111,
  0b11111,
  0b11111
};

const byte customChar_vol_4[8] = {//vol.4 graphic used in level setting
  0b00000,
  0b00000,
  0b00000,
  0b00000,
  0b11111,
  0b11111,
  0b11111,
  0b11111
};

byte customChar_vol_5[8] = {//vol.5 graphic used in level setting
  0b00000,
  0b00000,
  0b00000,
  0b11111,
  0b11111,
  0b11111,
  0b11111,
  0b11111
};

const byte customChar_vol_6[8] = {//vol.6 graphic used in level setting
  0b00000,
  0b00000,
  0b11111,
  0b11111,
  0b11111,
  0b11111,
  0b11111,
  0b11111
};

const byte customChar_vol_7[8] = {//vol.7 graphic used in level setting
  0b00000,
  0b11111,
  0b11111,
  0b11111,
  0b11111,
  0b11111,
  0b11111,
  0b11111
};

const byte customChar_play_icon[8] = {//vol.8 graphic used in level setting
  0b01000,
  0b01100,
  0b01110,
  0b01111,
  0b01111,
  0b01110,
  0b01100,
  0b01000
};

///////////////     object, instance    ///////////////////////////
ClickEncoder *encoder;
LiquidCrystal_I2C lcd(0x27, 16, 2); // I2C address 0x27, 16 column and 2 rows
///// ISD1700 instance  ///////////////
ISD1700 chipOne(3);//chip1, SS1 is pin 3
ISD1700 chipTwo(4);//chip2, SS2 is pin 4
ISD1700 chipThree(5);//chip3, SS3 is pin 5
ISD1700 chipFour(6);//chip4, SS4 is pin 6
ISD1700 chipFive(7);//chip5, SS5 is pin 7
ISD1700 chipSix(8);//chip6, SS6 is pin 8
ISD1700 chipSeven(9);//chip7, SS7 is pin 9
ISD1700 chipEight(10);//chip8, SS8 is pin 10
//AnalogMultiButton
AnalogMultiButton buttons(BUTTONS_PIN, BUTTONS_TOTAL, BUTTONS_VALUES, 12);//debouce = 10ms
// pass a fourth parameter to set the debounce time in milliseconds
// this defaults to 20 and can be increased if you're working with particularly bouncy buttons

//NeoPixel, Full color LEDs
Adafruit_NeoPixel strip(LED_COUNT, LED_PIN, NEO_GRB + NEO_KHZ800);

/////////////////     declaration of functions    ////////////////////////////// 
void timerIsr() {
  encoder->service();
}

////////////////////////////////////   Functions for Recording and Playing     /////////////////////////
void powerUpISD_all(){//power up all ISD1700 device
  Serial.println("------------------");
  chipOne.pu();
  Serial.println("ChipOne PU sent..");
  while(chipOne.CMD_ERR() == 1){
    Serial.print("CMD ERROR..,");
    chipOne.pu();
    Serial.println("PU sent again..");
  }
  delay(100);//Typ. TPUD=50ms
  Serial.println("PU accepted..");
  if(chipOne.INT() == 1){
    chipOne.clr_int();
    Serial.println("ChipOne INT cleared");
  }
  
  chipTwo.pu();
  Serial.println("ChipTwo PU sent..");
  while(chipTwo.CMD_ERR() == 1){
    Serial.print("CMD ERROR..,");
    chipTwo.pu();
    Serial.println("PU sent again..");
  }
  delay(100);//Typ. TPUD=50ms
  Serial.println("PU accepted..");
  if(chipTwo.INT() == 1){
    chipTwo.clr_int();
    Serial.println("ChipTwo INT cleared");
  }

  chipThree.pu();
  Serial.println("ChipThree PU sent..");
  while(chipThree.CMD_ERR() == 1){
    Serial.print("CMD ERROR..,");
    chipThree.pu();
    Serial.println("PU sent again..");
  }
  delay(100);//Typ. TPUD=50ms
  Serial.println("PU accepted..");
  if(chipThree.INT() == 1){
    chipThree.clr_int();
    Serial.println("ChipThree INT cleared");
  }

  chipFour.pu();
  Serial.println("ChipFour PU sent..");
  while(chipFour.CMD_ERR() == 1){
    Serial.print("CMD ERROR..,");
    chipFour.pu();
    Serial.println("PU sent again..");
  }
  delay(100);//Typ. TPUD=50ms
  Serial.println("PU accepted..");
  if(chipFour.INT() == 1){
    chipFour.clr_int();
    Serial.println("ChipFour INT cleared");
  }

  chipFive.pu();
  Serial.println("ChipFive PU sent..");
  while(chipFive.CMD_ERR() == 1){
    Serial.print("CMD ERROR..,");
    chipFive.pu();
    Serial.println("PU sent again..");
  }
  delay(100);//Typ. TPUD=50ms
  Serial.println("PU accepted..");
  if(chipFive.INT() == 1){
    chipFive.clr_int();
    Serial.println("ChipFive INT cleared");
  }

  chipSix.pu();
  Serial.println("ChipSix PU sent..");
  while(chipSix.CMD_ERR() == 1){
    Serial.print("CMD ERROR..,");
    chipSix.pu();
    Serial.println("PU sent again..");
  }
  delay(100);//Typ. TPUD=50ms
  Serial.println("PU accepted..");
  if(chipSix.INT() == 1){
    chipSix.clr_int();
    Serial.println("ChipSix INT cleared");
  }

  chipSeven.pu();
  Serial.println("ChipSeven PU sent..");
  while(chipSeven.CMD_ERR() == 1){
    Serial.print("CMD ERROR..,");
    chipSeven.pu();
    Serial.println("PU sent again..");
  }
  delay(100);//Typ. TPUD=50ms
  Serial.println("PU accepted..");
  if(chipSeven.INT() == 1){
    chipSeven.clr_int();
    Serial.println("ChipSeven INT cleared");
  }
  
  chipEight.pu();
  Serial.println("ChipEight PU sent..");
  while(chipEight.CMD_ERR() == 1){
    Serial.print("CMD ERROR..,");
    chipEight.pu();
    Serial.println("PU sent again..");
  }
  delay(100);//Typ. TPUD=50ms
  Serial.println("PU accepted..");
  if(chipEight.INT() == 1){
    chipEight.clr_int();
    Serial.println("ChipEight INT cleared");
  }

  while(chipOne.RDY() != 1){
  }
  Serial.println("chipOne Ready..");
  while(chipTwo.RDY() != 1){
  }
  Serial.println("chipTwo Ready..");
  while(chipThree.RDY() != 1){
  }
  Serial.println("chipThree Ready..");
  while(chipFour.RDY() != 1){
  }
  Serial.println("chipFour Ready..");
  while(chipFive.RDY() != 1){
  }
  Serial.println("chipFive Ready..");
  while(chipSix.RDY() != 1){
  }
  Serial.println("chipSix Ready..");
  while(chipSeven.RDY() != 1){
  }
  Serial.println("chipSeven Ready..");
  while(chipEight.RDY() != 1){
  }
  Serial.println("chipEight Ready..");
}

void configISD_all(){//only first time, set APC resister value in ISD chips and write it in their Non-volatile memory
  if(chipOne.rd_apc() != 0b0000100111100000){
     while(chipOne.RDY() != 1){
     }
     chipOne.wr_apc2(apc);
     while(chipOne.RDY() != 1){
     }
     chipOne.wr_nvcfg();
     while(chipOne.RDY() != 1){
     }
  }
  if(chipTwo.rd_apc() != 0b0000100111100000){
     while(chipTwo.RDY() != 1){
     }
     chipTwo.wr_apc2(apc);
     while(chipTwo.RDY() != 1){
     }
     chipTwo.wr_nvcfg();
     while(chipTwo.RDY() != 1){
     }
  }
  if(chipThree.rd_apc() != 0b0000100111100000){
     while(chipThree.RDY() != 1){
     }
     chipThree.wr_apc2(apc);
     while(chipThree.RDY() != 1){
     }
     chipThree.wr_nvcfg();
     while(chipThree.RDY() != 1){
     }
  }
  if(chipFour.rd_apc() != 0b0000100111100000){
     while(chipFour.RDY() != 1){
     }
     chipFour.wr_apc2(apc);
     while(chipFour.RDY() != 1){
     }
     chipFour.wr_nvcfg();
     while(chipFour.RDY() != 1){
     }
  }
  if(chipFive.rd_apc() != 0b0000100111100000){
     while(chipFive.RDY() != 1){
     }
     chipFive.wr_apc2(apc);
     while(chipFive.RDY() != 1){
     }
     chipFive.wr_nvcfg();
     while(chipFive.RDY() != 1){
     }
  }
  if(chipSix.rd_apc() != 0b0000100111100000){
     while(chipSix.RDY() != 1){
     }
     chipSix.wr_apc2(apc);
     while(chipSix.RDY() != 1){
     }
     chipSix.wr_nvcfg();
     while(chipSix.RDY() != 1){
     }
  }
  if(chipSeven.rd_apc() != 0b0000100111100000){
     while(chipSeven.RDY() != 1){
     }
     chipSeven.wr_apc2(apc);
     while(chipSeven.RDY() != 1){
     }
     chipSeven.wr_nvcfg();
     while(chipSeven.RDY() != 1){
     }
  }
  if(chipEight.rd_apc() != 0b0000100111100000){
     while(chipEight.RDY() != 1){
     }
     chipEight.wr_apc2(apc);
     while(chipEight.RDY() != 1){
     }
     chipEight.wr_nvcfg();
     while(chipEight.RDY() != 1){
     }
  }
}

void showISD_apc(){//Read APC resisters value of ISD chips and show them on Serial Monitor
  apc_ISDchipOne = chipOne.rd_apc();
  Serial.println(apc_ISDchipOne, BIN);
  apc_ISDchipTwo = chipTwo.rd_apc();
  Serial.println(apc_ISDchipTwo, BIN);
  apc_ISDchipThree = chipThree.rd_apc();
  Serial.println(apc_ISDchipThree, BIN);
  apc_ISDchipFour = chipFour.rd_apc();
  Serial.println(apc_ISDchipFour, BIN);
  apc_ISDchipFive = chipFive.rd_apc();
  Serial.println(apc_ISDchipFive, BIN);
  apc_ISDchipSix = chipSix.rd_apc();
  Serial.println(apc_ISDchipSix, BIN);
  apc_ISDchipSeven = chipSeven.rd_apc();
  Serial.println(apc_ISDchipSeven, BIN);
  apc_ISDchipEight = chipEight.rd_apc();
  Serial.println(apc_ISDchipEight, BIN);
}
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
void loop() {
  byte n;
  byte i;
  byte p;
  byte loop = 0;
  /////////////   update buttons and keys status with ADC  /////////////
  buttons.update();
  /*
  //please use this to determine ADC values for reading buttons and keys
  key = analogRead(BUTTONS_PIN);
  Serial.println(key);
  */
  ////////////   update rotary encorder status   ///////////////////
  value += encoder->getValue();
  //show_status();//show statsus for debuging, be noted that if showing status, real time playing in "play mode" is impossible

  /////////////////////// Process in TOP menu  //////////////////////////////////
  if(menu_column == 0){//TOP menu
    if(value != last){//when encorder value is updated
        if(value<0){
          value = 0;
        }
        else if(value>5){
          value = 5;
        }
        menu_row = value;
        display_menu(menu_column, value);
        if(value == 5){
          lcd.setCursor(0,1);
          lcd.print("        ");
        }
        Serial.println(value);      
    }    
    if(buttons.onPress(button_encoder)){//when encoder button is pressed
      if(menu_row == 1){//"Edit sound" is selected
        menu_column = 1;
        menu_row = 0;
        display_menu(menu_column, menu_row);
        value = 0;
      }
      else if(menu_row == 2){//"Edit rhythm" is selected
        menu_column = 5;
        menu_row = 0;
        display_menu(menu_column, menu_row);
        value = 0;
      }
      else if(menu_row == 3){//"Edit track" is selected
        menu_column = 5;
        menu_row = 1;
        display_menu(menu_column, menu_row);
        value = 0;
      }
      else if(menu_row == 4){//"BPM" is selected
        menu_column = 4;
        menu_row = 1;
        lcd.clear();
        lcd.home();
        display_menu(menu_column, menu_row);
        lcd.setCursor(3,0);
        lcd.print(" = ");
        lcd.print(bpm);
      }
      else if(menu_row == 5){//"Setting" is selected
        menu_column = 6;
        menu_row = 0;
        value = 0;
        display_menu(menu_column, menu_row);
      }
    }    
    if(menu_row == 0){//play sound when PLAY mode is selected
      if(buttons.isPressed(pad_1)){
        playROM_pad(1);
      }
      else if(buttons.isPressed(pad_2)){
        playROM_pad(2);
      }
      else if(buttons.isPressed(pad_3)){
        playROM_pad(3);
      }
      else if(buttons.isPressed(pad_4)){
        playROM_pad(4);
      }
      else if(buttons.isPressed(pad_5)){
        playROM_pad(5);
      }
      else if(buttons.isPressed(pad_6)){
        playROM_pad(6);
      }
      else if(buttons.isPressed(pad_7)){
        playROM_pad(7);
      }
      else if(buttons.isPressed(pad_8)){
        playROM_pad(8);
      }    
    }
  }

  /////////////////////// Process in selecting Sound  //////////////////////////////////
  else if(menu_column == 1){
    if(value != last){//when encorder value is updated
      if(value<0){
        value = 0;
      }
      else if(value>=7){
        value = 7;
      }
      chip_n = value + 1;
      display_menu(menu_column, menu_row);
    }

    if(buttons.onPress(button_encoder)){//when encoder button is pressed
      menu_column = 2;
      display_menu(menu_column, menu_row);
      chip_n = value +1;
      value = 0;
    }
    if(buttons.onRelease(pad_back)){//when back button is pressed
      menu_column = 0;
      menu_row = 1;
      value = 1;
      display_menu(menu_column, menu_row);
    }
  }
  
  /////////////////////// Process in selecting menu "play and trim" or "Sampling"  //////////////////////////////////
  else if(menu_column == 2){
    if(value != last){//when encorder value is updated
      if(value % 2 == 0){
        menu_row = 0;
        lcd.setCursor(0,1);
        lcd.print(F("  "));
        lcd.home();
        lcd.print(F("->"));
      }
      else{
        menu_row = 1;
        lcd.home();
        lcd.print(F("  "));
        lcd.setCursor(0,1);
        lcd.print(F("->"));
      }
    }
    if(buttons.onPress(button_encoder) && menu_row == 0){//when encoder button is pressed on selecting "play and trim" menu
      menu_column = 11;
      menu_row = 0;
      if(EEPROM.read(9 + 2*(chip_n - 1)) >= 16){
        Start_addr = EEPROM.read(9 + 2*(chip_n - 1));
      }
      else{
        Start_addr = 16;
      }
      if(EEPROM.read(10 + 2*(chip_n - 1)) >= 16){
        End_addr = EEPROM.read(10 + 2*(chip_n - 1));
      }
      else{
        End_addr = 16;
      }
      lcd.clear();
      lcd.home();
      lcd.print(F("->"));
      lcd.setCursor(2, 0);
      lcd.print(F("START:"));
      lcd.print(Start_addr);
      lcd.setCursor(2, 1);
      lcd.print(F("END:"));
      lcd.print(End_addr);
      lcd.setCursor(14, 0);
      lcd.print(F("S"));
      lcd.print(chip_n);
      value = EEPROM.read(9 + 2*(chip_n - 1));
      encoder->setAccelerationEnabled(true);
    }
    if(buttons.onPress(button_encoder) && menu_row == 1){//when encoder button is pressed on selecting "Sampling" menu
      menu_column = 3;
      menu_row = 0;
      lcd.clear();
      lcd.print(F("->"));
      lcd.print(F("Lo-Fi"));
      lcd.setCursor(2,1);
      lcd.print(F("Hi-Fi"));
      value = 0;
    }
    if(buttons.onRelease(pad_back)){//when back button is pressed
      menu_column = 1;
      display_menu(menu_column, menu_row);
      value = chip_n - 1;
    }
  }

  /////////////////////// Process in selecting "Lo-fi" or "Hi-Fi" in Sampling menu //////////////////////////////////
  else if(menu_column == 3){
    if(value != last){//when encorder value is updated
      if(value%2 == 0){
        lcd.setCursor(0,1);
        lcd.print("  ");
        lcd.home();
        lcd.print(F("->"));
      }
      else{
        lcd.home();
        lcd.print(F("  "));
        lcd.setCursor(0,1);
        lcd.print(F("->"));
      }
    }
    if(buttons.onPress(button_encoder) && menu_row == 0){//when encoder button is pressed
      if(value%2 == 0){//when selecting "Lo-Fi"
        bitWrite(REC_quality, chip_n - 1, 0);        
      }
      else{
        bitWrite(REC_quality, chip_n - 1, 1);
      }
      set_REC_quality(REC_quality & ~(1<<(chip_n -1)));
      menu_column = 4;
      menu_row = 0;
      lcd.setCursor(2, 0);
      lcd.print(F("start sampling"));
      switch(chip_n){
        case 1:
           chipOne.wr_apc2(0b0000100110100000);//enable Analog FT(feed through) of only ISD chip which will be recorded
           break;
        case 2:
           chipTwo.wr_apc2(0b0000100110100000);
           break;
        case 3:
           chipThree.wr_apc2(0b0000100110100000);
           break;
        case 4:
           chipFour.wr_apc2(0b0000100110100000);
           break;
        case 5:
           chipFive.wr_apc2(0b0000100110100000);
           break;
        case 6:
           chipSix.wr_apc2(0b0000100110100000);
           break;
        case 7:
           chipSeven.wr_apc2(0b0000100110100000);
           break;
        case 8:
           chipEight.wr_apc2(0b0000100110100000);
           break;
      }
      delay(100);
      lcd.setCursor(2,1);
      lcd.print(F("push Pad_"));
      lcd.setCursor(10,1);
      lcd.print(chip_n);
      value = 0;
    }
    if(buttons.onRelease(pad_back)){//when back button is pressed
      menu_column -= 1;
      menu_row = 0;
      display_menu(menu_column, menu_row);
      lcd.noBlink();    
    }
  }
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
